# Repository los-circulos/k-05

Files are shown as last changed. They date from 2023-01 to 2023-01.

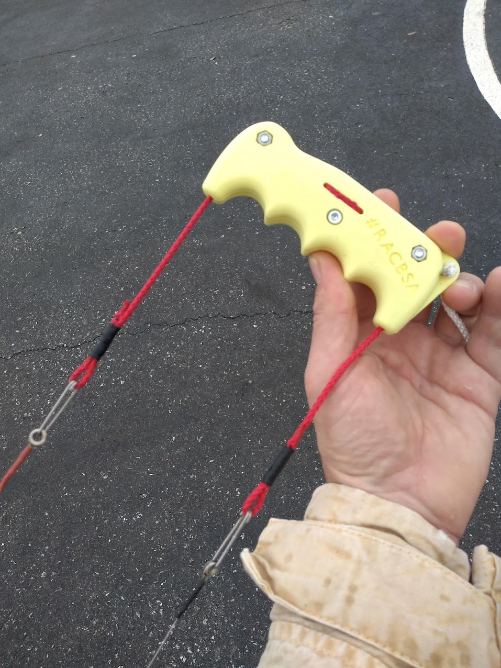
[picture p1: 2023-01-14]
images/handle-v3-field.png

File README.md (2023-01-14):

# k-05 3d print handle for control line airplane models

Based on control line handle design https://www.thingiverse.com/thing:4312610

Current version: V3 with adjustable offset

Recommended for up to 1 - 1.4kg / 2 - 3lbs airplanes, depending on material used for printing.
Simple PLA prints were tested up to 25-30kg pulls, including safety hook.

My print settings:
 - layer height: 0.12mm
 - wall count: 4
 - infill: cubic 20%

BOM:
 - 1* handle side piece "A"
 - 1* handle middle piece "B"
 - 1* handle side piece "C"
 - 2* M4*16 allen bolts
 - 1* M4*20 allen bolt
 - 3* M4 nut
 - 1m 3mm non-streching nylon chord
 - thread to make hooks on chord
 - epoxy to fix thread
 - optional: 6-8mm shrink wrap tube to cover threads
 - 2 "quick links" to attach cables

Assembly:
 - cautiosly drill bolt holes to 4mm (they are made for a tight fit)
 - cut chord to two pieces, a 400-450mm for the leads and rest for safety wrist hook
 - burn one end of each chord with a lighter, forming a "needle tip". This will help routing chord through holes
 - route the shorter chord through the holes in B - A - A - B (in this order, see photos). 
Chord should fit in the grove on side piece "A" and in the tunnels of middle piece "B"
 - assemble the 3 pieces with the 3 bolts
 - make hooks on both ends of the leadout cable. I prefer sawing the chord to itself to form a hook. 
 - make one hook on one end of the safety wrist hook
 - fix the threads with epoxy. Optionally cover threads with shrinkwraps
 - form a big hook with the small hook on the safety wrist hook chord
 - route chord through hole in the corner of middle piece "B"
 - make a big knot which prevents chord slipping back out of the hole. Burn knot with a lighter to fix it

Files:

 - handle-v3.blend - my blender project file, you should not need it
 - handle-v3-A-***.stl - personalized "A" pieces made for friends
 - handle-v3-A-uncut.stl - normal "A" piece - you can cut your own text in it
 - handle-v3-B.stl - middle "B" piece
 - handle-v3-C.stl - side "C" piece
 - LICENSE
 - README.md

@los.circulos
instagram.com/los.circulos
github.com/los-circulos
#controlline #vuelocircular #uコン #opensource

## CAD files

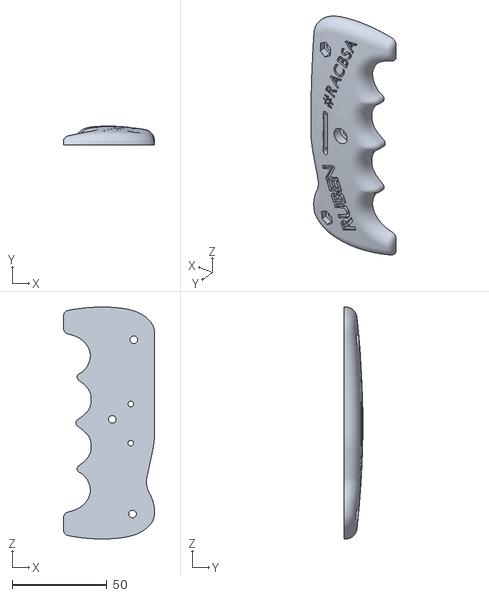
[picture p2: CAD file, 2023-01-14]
handle-v3-A-RUBEN.stl
48.0 x 9.90 x 122.2

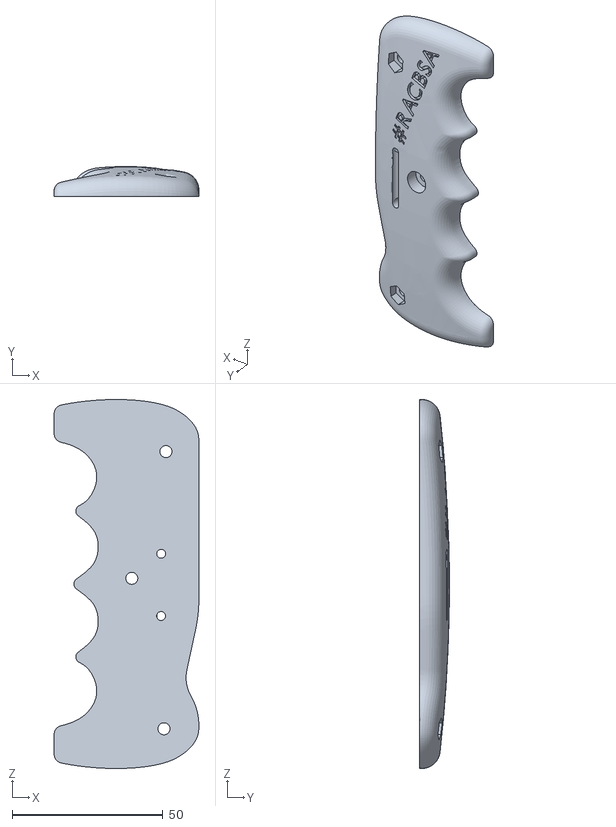
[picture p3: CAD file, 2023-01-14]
handle-v3-A-RACBSA.stl
48.0 x 9.90 x 122.2

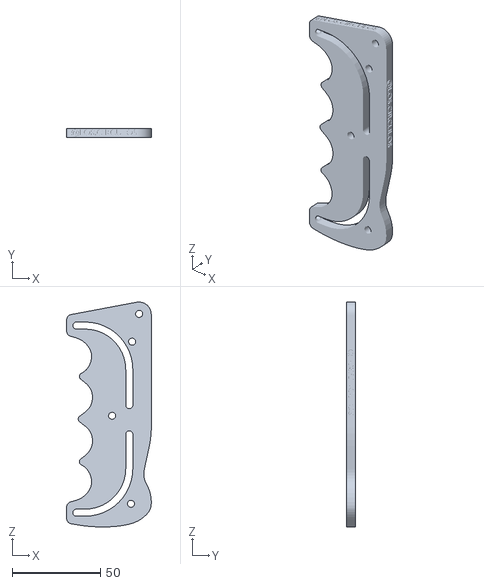
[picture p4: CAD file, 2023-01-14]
handle-v3-B.stl
48.0 x 5.00 x 127.5

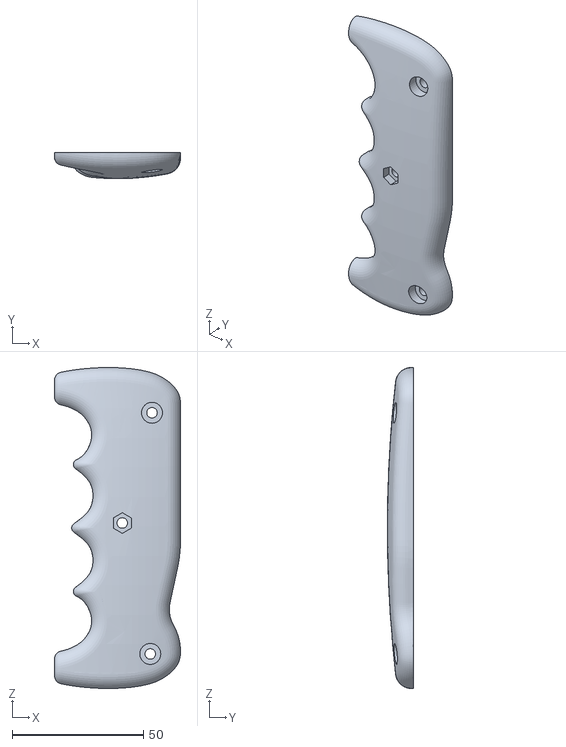
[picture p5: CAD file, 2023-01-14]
handle-v3-C.stl
48.0 x 9.83 x 122.2

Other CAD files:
handle-v3-A-uncut.stl
handle-v3-A-BPMSE.stl

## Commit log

2023-01-14 initial - V3 handle with adjustable offset
    [handle-v3-A-BPMSE.stl, handle-v3-A-RACBSA.stl, handle-v3-A-RUBEN.stl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]
2023-01-14 add photos, update BOM
